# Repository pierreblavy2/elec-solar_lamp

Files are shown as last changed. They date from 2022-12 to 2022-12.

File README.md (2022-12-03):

# Features
* A cheap very simple solar lamp. Can be 3D printed, or built in a glass jar.
* Automatically switch on/of the light when night/day comes
* Solar
* Can be switched off manualy, and used as a torch
* Printable circuit board (KiCad), can easily be done on perfboard too.

# Pictures
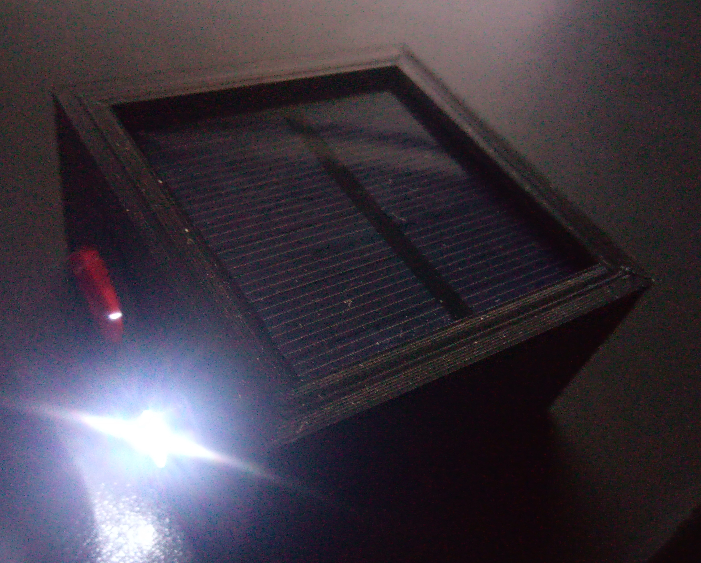
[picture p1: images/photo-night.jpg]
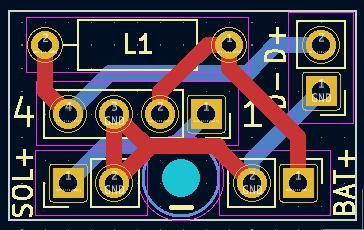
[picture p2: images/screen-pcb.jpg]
  

# Components

|Name|Quantity|Description|
|---|---|---|
|QX5252|1|https://datasheetspdf.com/pdf/719492/Qxmd/QX5252/1|
|AAA_holder|1|AAA battery holder|
|Solar_panel|1|60x60 mm, 5V|
|5mm LED|1|20mA LED|
|330uH|1|Inductance DIP (1)|
|Switch|1|20mm, toggle, on/off (2)|
|5mm LED support|1|RTM5021|

(1) Inductance values control the currant going trough the LED, according to this table. The default value is 330 uH. Lower inductince will increase light brightness and decrease battery duration.

|Inductance (uH)|Current (mA)|
|---|---|
|330|11|
|270|14.5|
|220|15.5|
|150|25|
|100|34.5|
|82|38|
|56|50|
|47|75|
|33|110|

(2) The switch is mounted in series with the LED

# Circuit
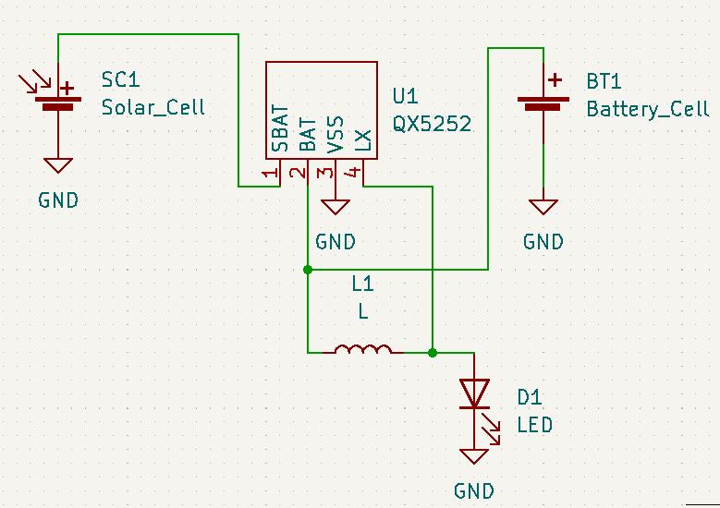
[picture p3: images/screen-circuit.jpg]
 

# License
This project is licensed under the [LGPL-v3 license](https://www.gnu.org/licenses/lgpl-3.0.txt).

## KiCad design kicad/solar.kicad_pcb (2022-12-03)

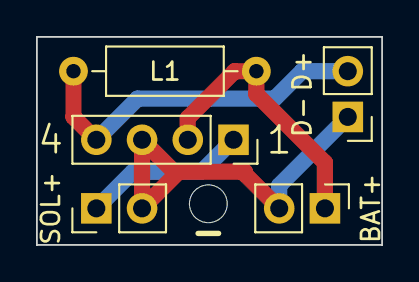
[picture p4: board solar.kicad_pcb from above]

Board: 2 copper layers, 19.2 x 11.6 mm, 5 parts (0 on the bottom side), 4 nets.

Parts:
1: QX5252; PinSocket_1x04_P2.54mm_Vertical
BT1: Battery_Cell; PinHeader_1x02_P2.54mm_Vertical
D1: LED; PinHeader_1x02_P2.54mm_Vertical
L1: L; R_Axial_DIN0207_L6.3mm_D2.5mm_P10.16mm_Horizontal
SC1: Solar_Cell; PinHeader_1x02_P2.54mm_Vertical

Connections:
GND: 1.3 (VSS), BT1.2 (-), D1.1 (K), SC1.2 (-)
unnamed: 1.2 (BAT), BT1.1 (+), L1.1
unnamed: 1.4 (LX), D1.2 (A), L1.2
unnamed: 1.1 (SBAT), SC1.1 (+)
